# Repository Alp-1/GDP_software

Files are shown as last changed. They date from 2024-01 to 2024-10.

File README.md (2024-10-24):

banner-nana

This project aims to develop a rover that can navigate through different terrain in a forest environment autonomously.
The wiki containing more informatin about the rover can be found [here](https://github.com/Alp-1/NANA-Forest-Rover/wiki).

A more detailed account of the development process can be found [here](https://alportakci.com/projects/).

## The directory layout

    .
    ├── .vscode                 # VS Code settings
    ├── CAD Models              # CAD Models used in the project with attributions. 
    ├── ESP32                   # ESP32 code for ESP32-C3 dronebridge.
    ├── GPS                     # Script to start NTRIP caster.
    ├── low_level_control       # Low level control
    ├── lua_scripts             # Lua scripts uploaded in flight controller
    ├── navigation              # Autonomous navigation
    ├── pyrealsense             # Intel Realsense library required on Raspberry Pi
    ├── schematic               # Schematic of the low level controller
    ├── .gitignore
    ├── pyproject.toml          # Python dependencies
    └── README.md

### Installation
To run some code that are not hardware dependent on your local PC, you can run the following commands in Python (Version used: **3.10.5** in PC and Raspberry Pi):

(./ is the repo root directory)
```sh
$ pip install -e .
```

## Low Level Control
There are two components in the low level control i.e. the motor controller and the central hub. They are both implemented on the Raspberry Pi Pico using micropython. See the [README.md](low_level_control/README.md) in the low level control folder for more information.

## Autonomous navigation
The files in the pyrealsense folder may have to be in the same directory as the navigation scripts, depending on your installation.
Another option is to include the right package from local directory i.e. 
```python
from pyrealsense import pyrealsense2 as rs
``` 
To run the autonomous navigation script, use the following command in the navigation folder:
```sh
$ python navigation_final.py
```
## Research Poster

Poster

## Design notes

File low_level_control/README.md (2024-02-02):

# Low Level Control

There are two components in the low level control i.e. the motor controller and the central hub. They are both implemented on the Raspberry Pi Pico using micropython.

## The directory layout

    .
    ├── central_hub             # Central hub code
    ├── motor_controller        # Motor controller code
    ├── upy_mavlink             # MAVLink library for MicroPython
    ├── user_interface          # Output interface e.g. LED, RGB LED
    ├── protocol.py             # The protocol between the central hub and the motor controller.
    ├── tests                   # Tests that can be executed on host machine.
    └── README.md

## Loading/Running code on Pi Pico (IMPORTANT)
To load the code onto the Pi Pico, it is recommended to use Thonny IDE as they provide a GUI for the filesystem on the Pico. You can also use the command line tools (e.g. mpremote, rshell) to load the code onto the Pico.

First, load the common `user_interface` folder and `protocol.py` file onto the pico then load either the `motor_controller` or `central_hub` folder onto the pico depends on which component you want to run. Then, add respective `main.py` file to the root directory of the pico.

## Motor Controller
The motor controller is responsible for controlling the motors and reading off the sensors attached to the motor i.e. encodes and current sensors. It controls the motor using Sabertooth 2x12A through packetised serial protocol. The current sensors (ACS711EX) feeds ADC into the Pi Pico. The encoders are decoded in hardware using the Pi Pico's PIO.

## Central Hub
The central hub is responsible for controlling the modes of operation and the communication between the motor controller and the flight controller. This implementation offers three levels of autonomy i.e. direct RC control, Flight controller aided and fully autonomous mode. In all of these modes the Radio controller must be connected at all time.

## Running tests
The tests are implemented using pytest. To run the tests, run the following command in the root directory of the repo:
```sh
$ pytest
```
Alternatively, you can run the tests in vscode through the Testings tab.

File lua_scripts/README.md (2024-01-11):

# Lua Script

This folder contains the lua script used in this project

## Scripts
[rover-TerrainDetector.lua](https://github.com/ArduPilot/ardupilot/blob/master/libraries/AP_Scripting/examples/rover-TerrainDetector.lua) is used to slow down the rover when it encounters rough terrain.

- change the 'SPEED' parameter to change the value of speed of rough terrain. 

[rover-quicktune.lua](https://github.com/ArduPilot/ardupilot/blob/master/libraries/AP_Scripting/applets/rover-quicktune.lua) is used to tune the steering and speed controller gains for rover.
- The rover needs to be put in CIRCLE flight mode which is not achievable with QGround Control. Mission Planner is needed in this scenario.

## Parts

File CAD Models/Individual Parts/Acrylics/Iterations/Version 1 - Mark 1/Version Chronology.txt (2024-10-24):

formanufacture.zip
correctedmanufacture.zip
ForManufactureCDR.zip
23CDR.zip
Re23CDR.zip
fix.zip
ResSheld.cdr
Frontdraw v0.cdr

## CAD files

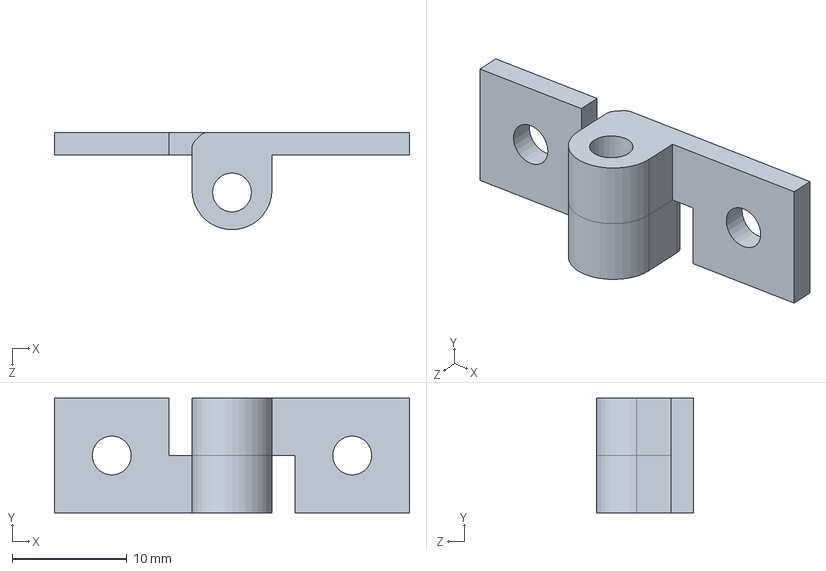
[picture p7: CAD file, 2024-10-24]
CAD Models/Individual Parts/Makerbeams/MakerBeam-hinge.SLDASM
31.0 x 10.0 x 8.50 mm
MakerBeam-hinge x 2

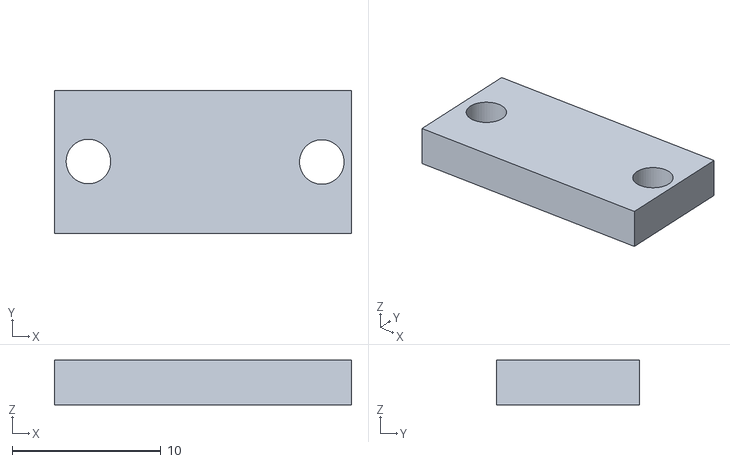
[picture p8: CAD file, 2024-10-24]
CAD Models/3D Print/cable holder v1.stl
20.0 x 9.60 x 3.00

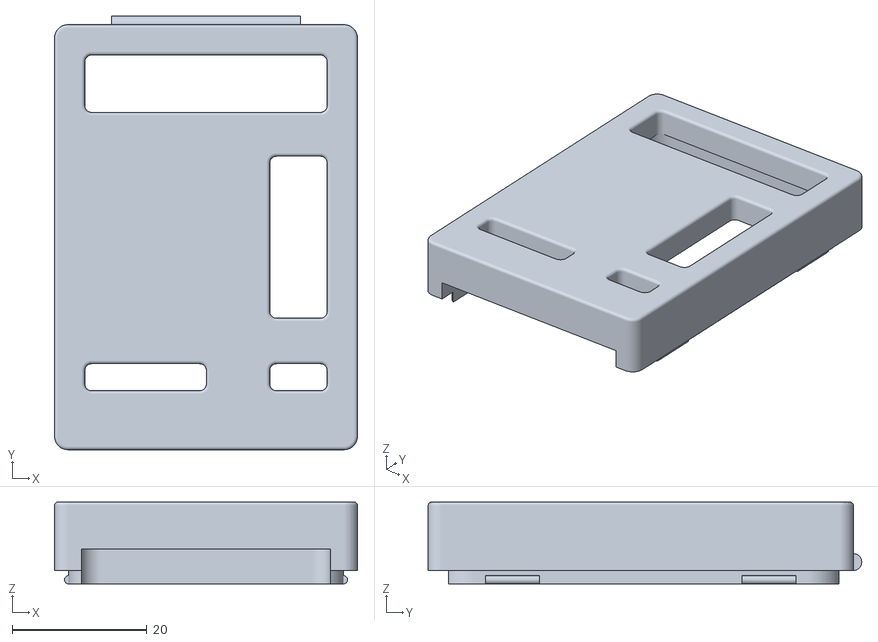
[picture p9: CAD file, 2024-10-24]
CAD Models/3D Print/Flight Controller Snap Mount/Top.stl
44.9 x 64.2 x 12.1

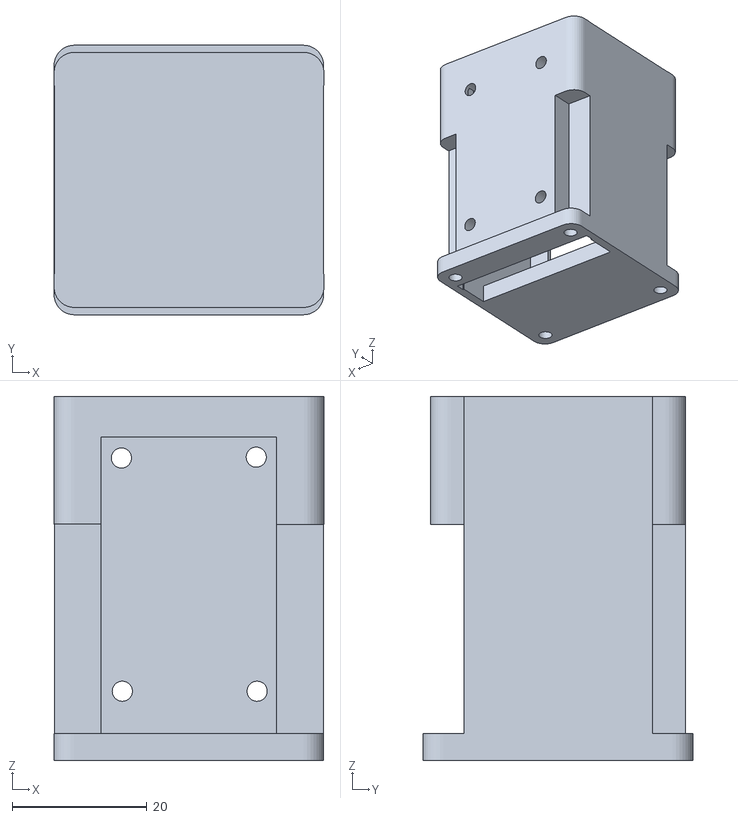
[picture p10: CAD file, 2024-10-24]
CAD Models/3D Print/Optical Flow/Optical Cube mk2.stl
40.1 x 40.0 x 54.0

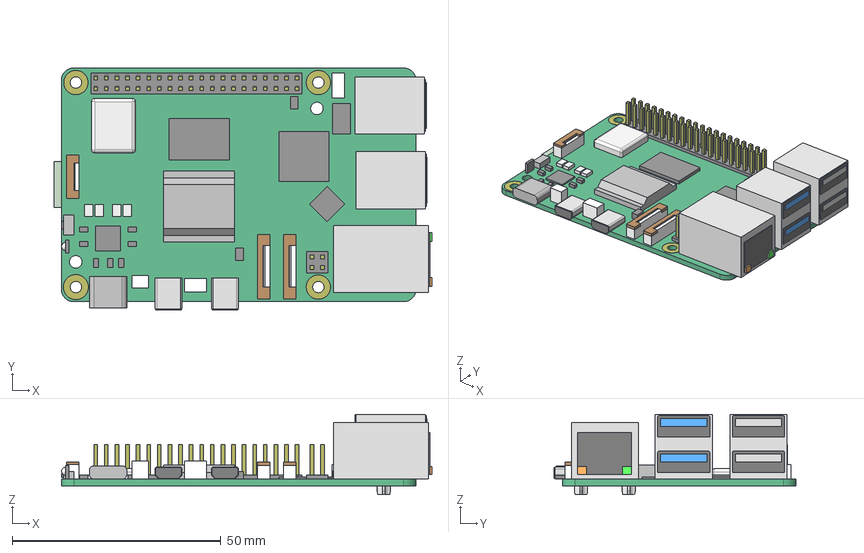
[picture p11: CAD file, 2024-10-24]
CAD Models/Individual Parts/Components/raspberry-pi-5-sbc-simple.step
90.6 x 58.0 x 19.2 mm
connector
CSI_DSI_connector x 2
ethernet
gpio
hdmi-micro x 2
IR
mounting-holes
pcb
pcba-components Geometry
chips
pcie
pmic
poe Geometry
poe-pins
pwr-connector
rp1
sd-card
switch
uart
usb-2-bank Geometry
usb2-port x 2
usb-3-bank Geometry
usb3-port x 2
usb-c

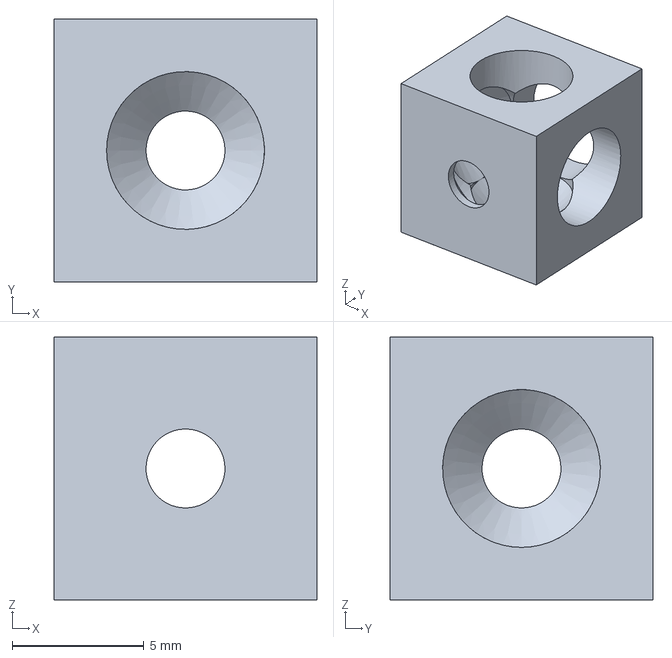
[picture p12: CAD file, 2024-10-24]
CAD Models/Individual Parts/Makerbeams/corner.stp
10.0 x 10.0 x 10.0 mm

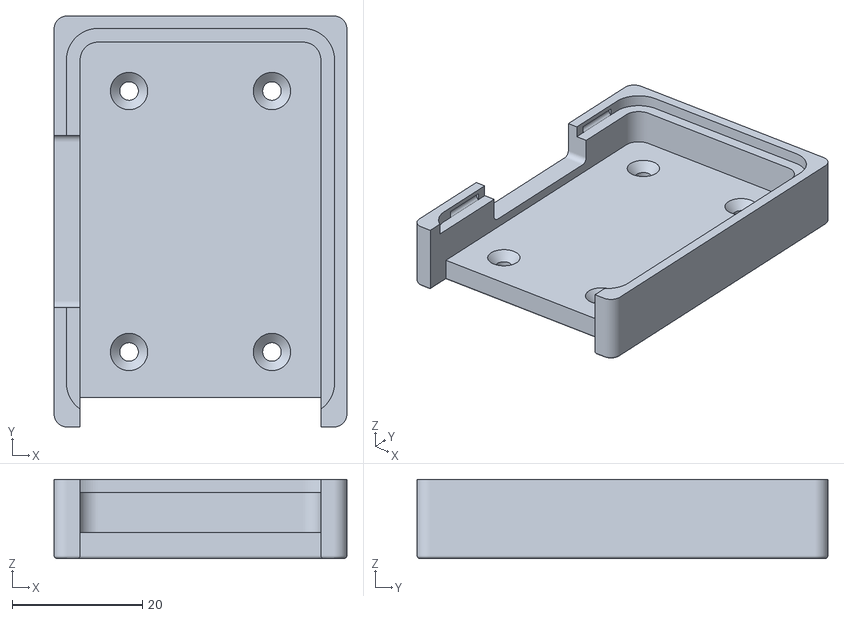
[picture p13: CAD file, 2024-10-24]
CAD Models/3D Print/Flight Controller Snap Mount/Bottom.stl
44.9 x 63.0 x 12.1

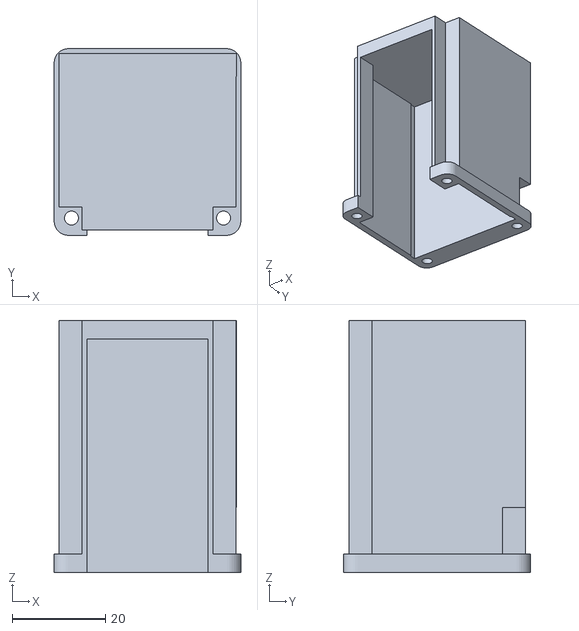
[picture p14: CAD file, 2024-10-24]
CAD Models/3D Print/Optical Flow/Optical Cube v1.stl
40.0 x 40.0 x 54.0

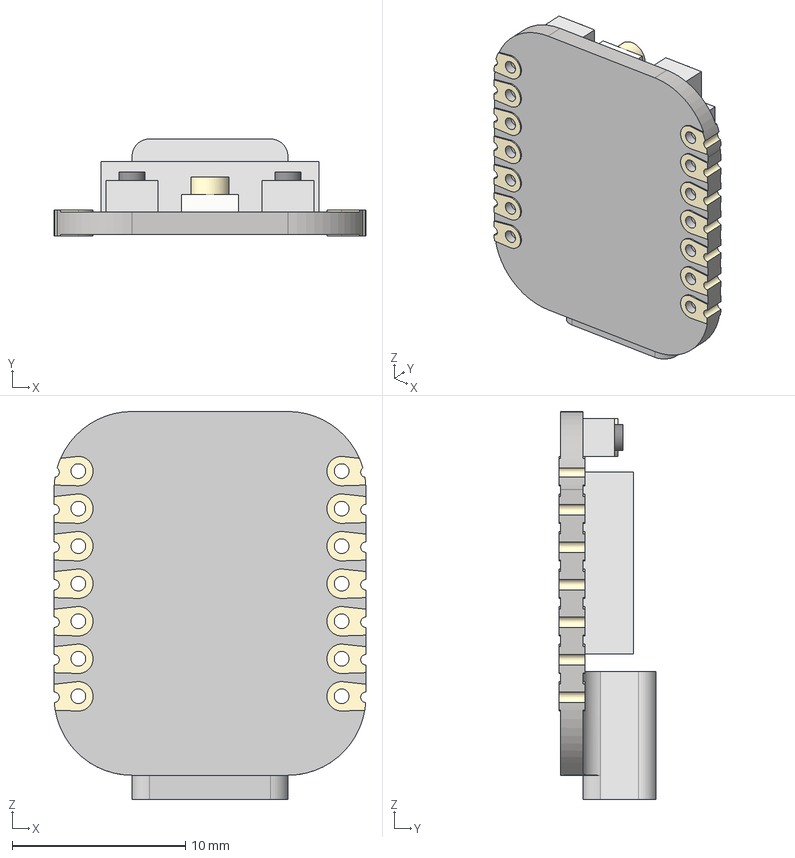
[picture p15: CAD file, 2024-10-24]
CAD Models/Individual Parts/Components/SEEED Esp32 C3 mini v2.step
18.0 x 5.60 x 22.4 mm

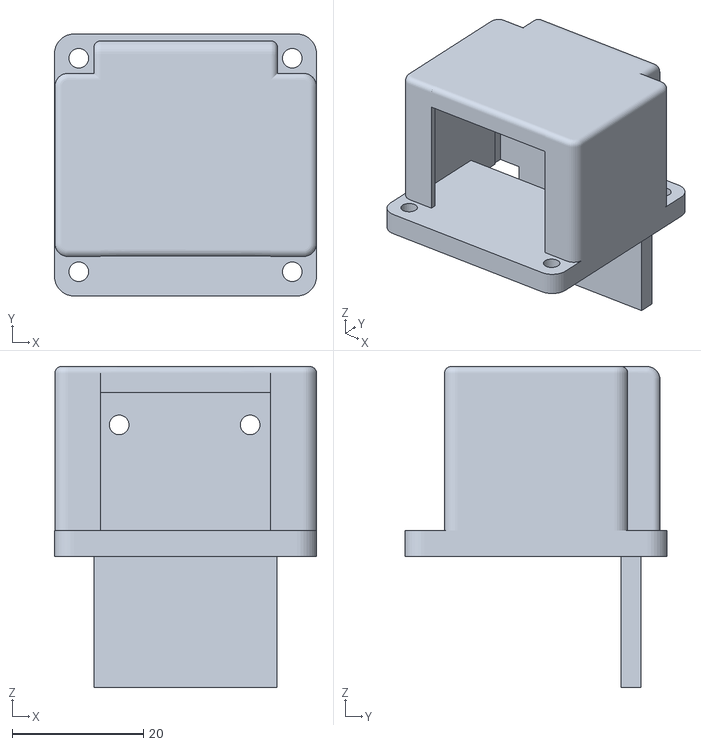
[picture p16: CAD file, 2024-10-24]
CAD Models/3D Print/Optical Flow/Optical Cube mk1 v4.stl
40.0 x 40.0 x 49.0

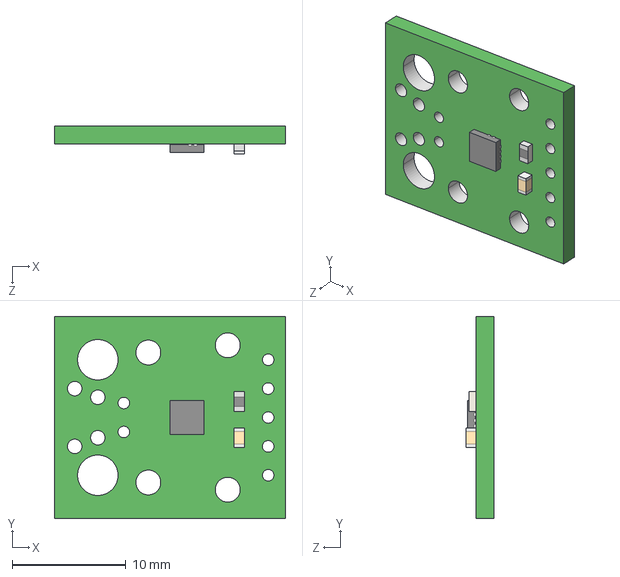
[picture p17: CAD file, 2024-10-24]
CAD Models/Individual Parts/Components/acs711ex-current-sensor-carrier.step
20.3 x 17.8 x 2.47 mm

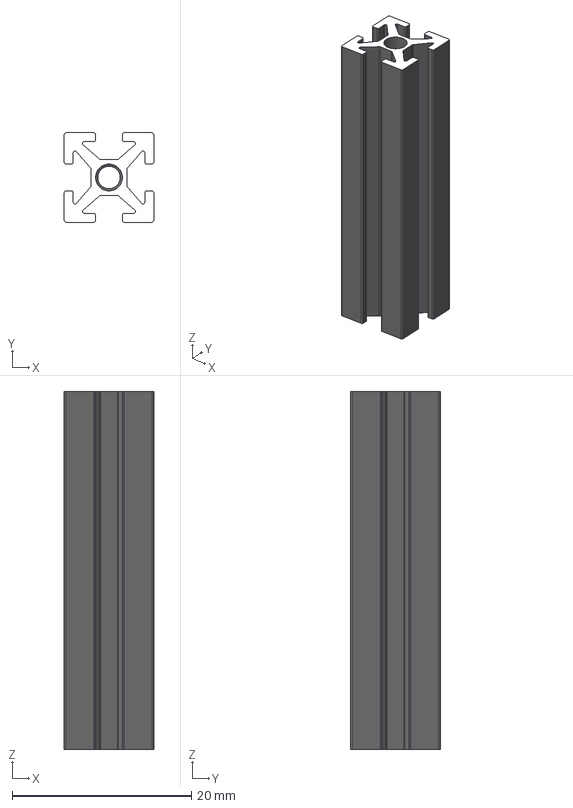
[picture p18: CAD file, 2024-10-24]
CAD Models/Individual Parts/Makerbeams/corner40.stp
10.0 x 10.0 x 40.0 mm

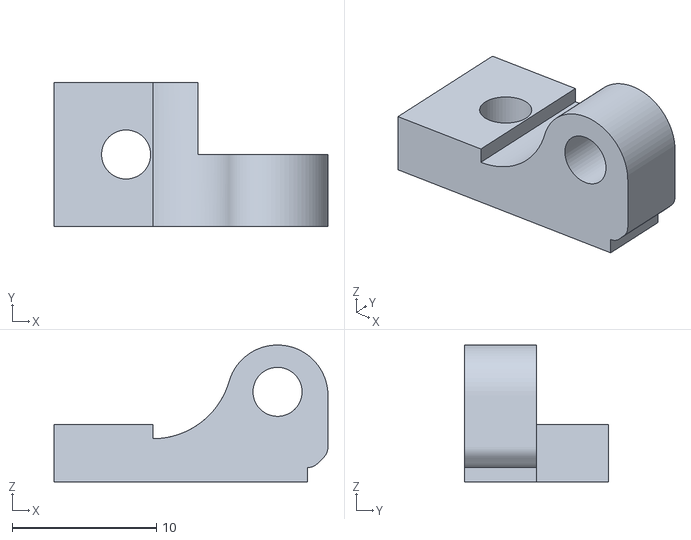
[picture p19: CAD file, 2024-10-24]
CAD Models/Individual Parts/Makerbeams/MakerBeam-hinge v2.stl
19.0 x 10.0 x 9.50

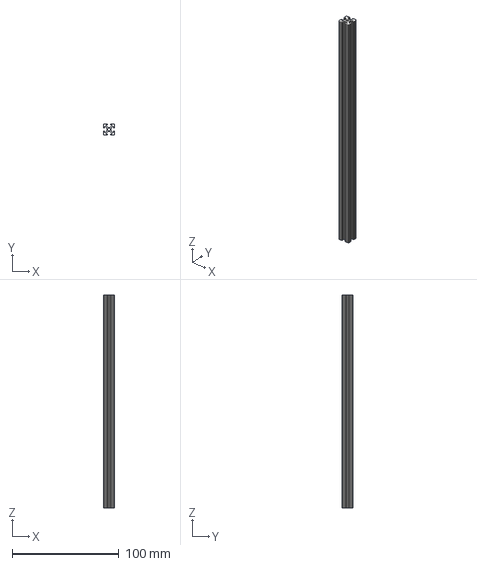
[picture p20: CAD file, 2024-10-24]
CAD Models/Individual Parts/Makerbeams/corner2.stp
10.0 x 10.0 x 200.0 mm

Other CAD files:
CAD Models/Individual Parts/Makerbeams/eye_plate_gs3212-05.stp
CAD Models/Individual Parts/Makerbeams/Makerbeam_T-Slot_Nut.step
CAD Models/3D Print/Cable Housing v2.f3z
CAD Models/3D Print/Optical Flow/Optical Cube mk1 v4.f3d
CAD Models/Individual Parts/Acrylics/Models/Front-Back v25.f3z
CAD Models/Individual Parts/Acrylics/Models/Front-Back1 v2.f3z
CAD Models/Individual Parts/Acrylics/Models/Side Panels v22.f3d
CAD Models/Individual Parts/Acrylics/Models/Top Cover v7.f3d
CAD Models/Individual Parts/Acrylics/Models/mount v12.f3d
CAD Models/Individual Parts/Acrylics/Models/rubber seal v1.f3d
CAD Models/Individual Parts/Acrylics/Models/shelf down v2.f3d
CAD Models/Individual Parts/Acrylics/Models/shelf small v2.f3d
CAD Models/Individual Parts/Aluminium Plates/Back v6.f3d
CAD Models/Individual Parts/Aluminium Plates/top half mount v2.f3d
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

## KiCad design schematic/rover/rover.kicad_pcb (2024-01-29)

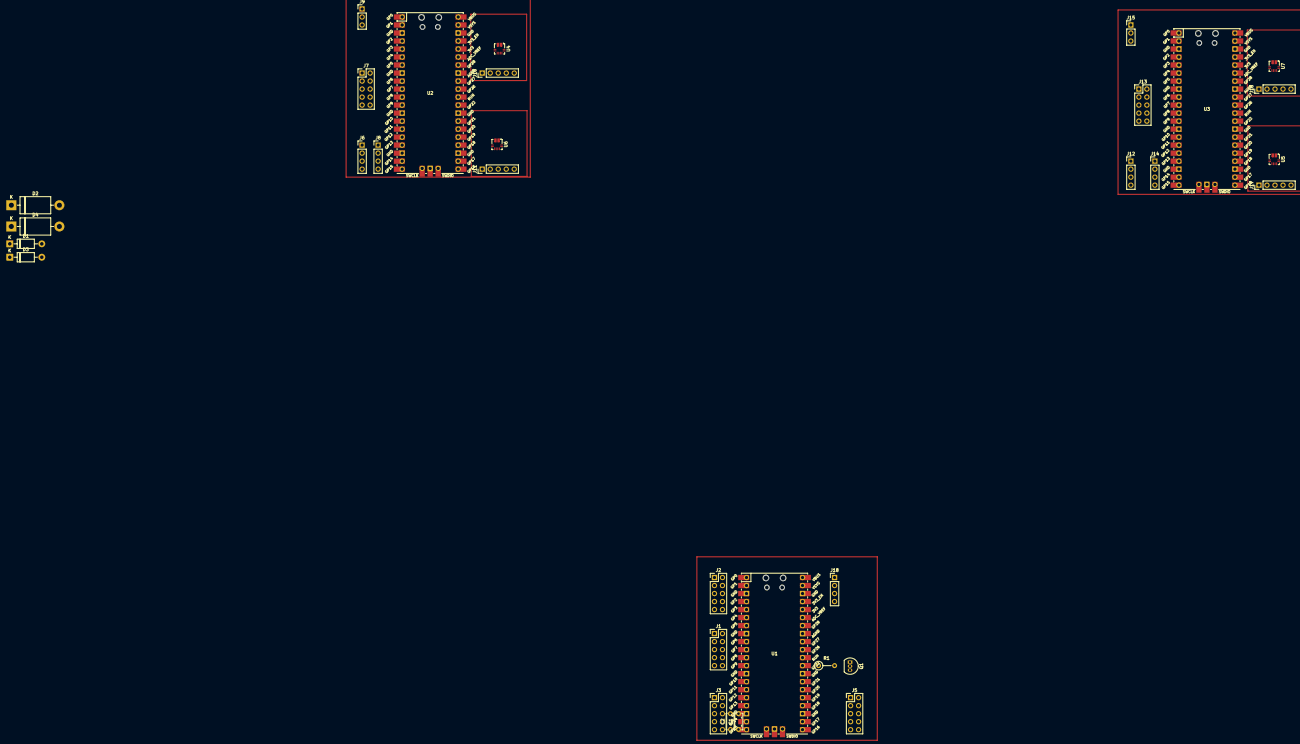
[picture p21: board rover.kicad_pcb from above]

Board: 2 copper layers, 32 parts (0 on the bottom side), 34 nets, no tracks yet.

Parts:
C1, C2: 3.3n; C_Disc_D5.0mm_W2.5mm_P5.00mm
D1, D3: 1N4733A; D_DO-41_SOD81_P10.16mm_Horizontal
D2, D4: 1N5820; D_DO-201AD_P15.24mm_Horizontal
J1: Front_Wheel_Conn; PinHeader_2x05_P2.54mm_Vertical
J2: Rear_Wheel_Conn; PinHeader_2x05_P2.54mm_Vertical
J3: Flight_Controller_Conn; PinHeader_2x05_P2.54mm_Vertical
J5: Receiver_Conn; PinHeader_2x05_P2.54mm_Vertical
J6, J12: Left_Encoder; PinHeader_1x04_P2.54mm_Vertical
J7, J13: Conn_02x05_Odd_Even; PinHeader_2x05_P2.54mm_Vertical
J8, J14: Right_Encoder; PinHeader_1x04_P2.54mm_Vertical
J9, J15: Conn_01x03_Socket; PinHeader_1x03_P2.54mm_Vertical
J10, J16: Right_Current_Sense; PinHeader_1x05_P2.54mm_Vertical
J11, J17: Left_Current_Sense; PinHeader_1x05_P2.54mm_Vertical
J18: Conn_01x04_Socket; PinHeader_1x04_P2.54mm_Vertical
Q1: BC547; TO-92_Inline
R1: 100k; R_Axial_DIN0207_L6.3mm_D2.5mm_P5.08mm_Vertical
U1, U2, U3: Pico; RPi_Pico_SMD_TH
U4, U5, U6, U7: ACS711xEXLT-31AB; Allegro_QFN-12-10-1EP_3x3mm_P0.5mm

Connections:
+3.3V: J5.3, J6.3, J8.3, J10.3, J11.3, J12.3, J14.3, J16.3, J17.3, U1.36 (3V3), U2.36 (3V3), U3.36 (3V3), U4.10 (VCC), U5.10 (VCC), U6.10 (VCC), U7.10 (VCC)
+5V: J9.1, J15.1, J18.2, U1.39 (VSYS)
/low level control/+5V_in: D2.1 (K), U2.39 (VSYS), U3.39 (VSYS)
/low level control/Sabertooth_front/S1: J9.2, U2.1 (GPIO0)
/low level control/Sabertooth_front/S2: J18.4, Q1.1 (C)
/low level control/Sabertooth_rear/S1: J15.2, U3.1 (GPIO0)
/low level control/central_hub/FC__SBUS: J3.1, J5.1
/low level control/central_hub/FC__Throttle_Left: C1.1, J3.8, U1.19 (GPIO14)
/low level control/central_hub/FC__Throttle_Right: C2.1, J3.10, U1.20 (GPIO15)
/low level control/central_hub/Flight_Controller__RX: J3.7, U1.22 (GPIO17)
/low level control/central_hub/Flight_Controller__TX: J3.9, U1.21 (GPIO16)
/low level control/central_hub/Front_Controller__RX: J1.8, J7.8, U1.2 (GPIO1), U2.6 (GPIO4)
/low level control/central_hub/Front_Controller__TX: J1.10, J7.10, U1.1 (GPIO0), U2.7 (GPIO5)
/low level control/central_hub/NeoPixelRGB: J18.1, U1.32 (GPIO27_ADC1)
/low level control/central_hub/OUTA_Left__Front: J1.7, J6.4, J7.7, U1.7 (GPIO5), U2.16 (GPIO12)
/low level control/central_hub/OUTA_Left__Rear: J2.7, J3.3, J12.4, J13.7, U1.14 (GPIO10), U3.16 (GPIO12)
/low level control/central_hub/OUTA_Right__Front: J1.6, J7.6, J8.4, U1.5 (GPIO3), U2.20 (GPIO15)
/low level control/central_hub/OUTA_Right__Rear: J2.6, J3.4, J13.6, J14.4, U1.17 (GPIO13), U3.20 (GPIO15)
/low level control/central_hub/OUTB_Left__Front: J1.9, J6.1, J7.9, U1.6 (GPIO4), U2.17 (GPIO13)
/low level control/central_hub/OUTB_Left__Rear: J2.9, J3.5, J12.1, J13.9, U1.15 (GPIO11), U3.17 (GPIO13)
/low level control/central_hub/OUTB_Right__Front: J1.4, J7.4, J8.1, U1.4 (GPIO2), U2.19 (GPIO14)
/low level control/central_hub/OUTB_Right__Rear: J2.4, J3.2, J13.4, J14.1, U1.16 (GPIO12), U3.19 (GPIO14)
/low level control/central_hub/Rear_Controller__RX: J2.8, J13.8, U1.12 (GPIO9), U3.6 (GPIO4)
/low level control/central_hub/Rear_Controller__TX: J2.10, J13.10, U1.11 (GPIO8), U3.7 (GPIO5)
/low level control/central_hub/Receiver__PPM: J5.2, U1.27 (GPIO21)
/power supply/5V_RaspberryPi: D3.1 (K), D4.2 (A)
GND: C1.2, C2.2, D1.2 (A), D3.2 (A), J1.2, J2.2, J3.6, J5.5, J6.2, J7.2, J8.2, J9.3, J10.1, J10.2, J11.1, J11.2, J12.2, J13.2, J14.2, J15.3, J16.1, J16.2, J17.1, J17.2, J18.3, Q1.3 (E), U1.3 (GND), U1.8 (GND), U1.13 (GND), U1.18 (GND), U1.23 (GND), U1.28 (GND), U1.38 (GND), U2.3 (GND), U2.18 (GND), U2.23 (GND), U2.28 (GND), U2.38 (GND), U3.3 (GND), U3.18 (GND), U3.23 (GND), U3.28 (GND), U3.38 (GND), U4.3 (GND), U5.3 (GND), U6.3 (GND), U7.3 (GND)
unnamed: D1.1 (K), D2.2 (A)
unnamed: J10.4, U2.32 (GPIO27_ADC1), U6.9 (VIOUT)
unnamed: J11.4, U2.34 (GPIO28_ADC2), U4.9 (VIOUT)
unnamed: J16.4, U3.32 (GPIO27_ADC1), U7.9 (VIOUT)
unnamed: J17.4, U3.34 (GPIO28_ADC2), U5.9 (VIOUT)
unnamed: Q1.2 (B), R1.2
unnamed: R1.1, U1.29 (GPIO22)

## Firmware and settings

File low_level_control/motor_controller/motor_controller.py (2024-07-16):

"""The main motor controller code"""

import time
from machine import Pin, UART
from motor_controller.motor_sensor import MotorSensing
from motor_controller.sabertooth import Sabertooth
from motor_controller.pid import PID
from protocol import Commands
from user_interface.led import OnBoardLED

LEFT_MOTOR_ID = 2
LEFT_MOTOR_ENCODER_PIN = 12
LEFT_MOTOR_SM = 0
LEFT_MOTOR_CURRENT_PIN = 1

RIGHT_MOTOR_ID = 1
RIGHT_MOTOR_ENCODER_PIN = 14
RIGHT_MOTOR_SM = 1
RIGHT_MOTOR_CURRENT_PIN = 2

CENTRAL_HUB_TX_PIN = 4
CENTRAL_HUB_RX_PIN = 5

SABERTOOTH_ADDRESS = 128
SABERTOOTH_BAUDRATE = 9600
SABERTOOTH_TX_PIN = 0
SABERTOOTH_RX_PIN = 1  # Irrelevant

BYPASS_ENCODER = True  # Remove this switch after encoder is fixed


class MotorController:
    """Controls the motor speed using the signals coming from the central hub"""

    THRESHOLD_CURRENT = 15  # Amps
    # Need to be at least twice the encoders' measurement time
    PID_PERIOD_MS = 200
    MAIN_LOOP_PERIOD_MS = 1
    SENSOR_UPDATE_PERIOD_MS = 1000
    # Period before the central hub is considered disconnected
    CENTRAL_HUB_TIMEOUT_MS = 1000

    # Speed setpoint range
    MAX_SPEED_RPM = 165
    MIN_SPEED_RPM = -165
    # The maximum range of the PID controller
    MAX_PID_RANGE = (MIN_SPEED_RPM, MAX_SPEED_RPM)
    PID_DEADZONE = 5

    # Attribute to reverse the output of the motor
    # to compensate for the motor being mounted in reverse
    REVERSE_OUTPUT = True

    # Motor driver drive modes
    MIXED = 0
    INDEPENDENT_MOTOR = 1

    def __init__(
        self,
        motor_driver_serial=None,
        central_hub_interface=None,
        left_motor=None,
        right_motor=None,
        motor_driver=None,
    ):
        """Initialize the motor controller.
        The parameters are used for testing purposes,
        please use the default values for normal operation."""
        # Initialize the motors
        self.motor_driver_serial = (
            UART(
                0,
                baudrate=SABERTOOTH_BAUDRATE,
                tx=Pin(SABERTOOTH_TX_PIN),
                rx=Pin(SABERTOOTH_RX_PIN),
            )
            if motor_driver_serial is None
            else motor_driver_serial
        )
        self.left_motor = (
            MotorSensing(
                LEFT_MOTOR_ENCODER_PIN,
                LEFT_MOTOR_SM,
                LEFT_MOTOR_CURRENT_PIN,
                invert_current=True,
            )
            if left_motor is None
            else left_motor
        )
        self.right_motor = (
            MotorSensing(
                RIGHT_MOTOR_ENCODER_PIN,
                RIGHT_MOTOR_SM,
                RIGHT_MOTOR_CURRENT_PIN,
                invert_current=True,
            )
            if right_motor is None
            else right_motor
        )
        self.motor_driver: Sabertooth = (
            Sabertooth(
                self.motor_driver_serial,
                address=SABERTOOTH_ADDRESS,
            )
            if motor_driver is None
            else motor_driver
        )
        self.central_hub_interface = (
            UART(
                1,
                baudrate=4800,
                tx=Pin(CENTRAL_HUB_TX_PIN),
                rx=Pin(CENTRAL_HUB_RX_PIN),
            )
            if central_hub_interface is None
            else central_hub_interface
        )

        self.left_speed_command = 0
        self.right_speed_command = 0
        self.turn = 0
        self.mixed_clipped_range = (-100, 100)

        self.current_drive_mode = self.MIXED

        self.pid_left = PID(
            Kp=0.25,
            Ki=0.001,
            Kd=0.005,
            setpoint=0,
            sample_time=self.PID_PERIOD_MS,
            output_limits=self.MAX_PID_RANGE,
            time_fn=time.ticks_ms,
        )
        self.pid_right = PID(
            Kp=0.25,
            Ki=0.001,
            Kd=0.005,
            setpoint=0,
            sample_time=self.PID_PERIOD_MS,
            output_limits=self.MAX_PID_RANGE,
            time_fn=time.ticks_ms,
        )

    def drive(self, left_speed: float, right_speed: float, turn=None):
        """Drive the motors at a given speed

        Parameters
        ----------
        left_speed: float
            The speed to drive the left motor at (-100: full reverse, 0: stop, 100: full forward)
        right_speed: float
            The speed to drive the right motor at (-100: full reverse, 0: stop, 100: full forward)
        turn: float
            The turn value (-100: full left, 0: straight, 100: full right)
            If this is not None, the rover will be driven in mixed mode
            using only values from left_speed and turn, i.e. the
            right_speed value will be ignored. (Assume this only happens in RC mode)
        """
        if self.REVERSE_OUTPUT:
            left_speed = -left_speed
            right_speed = -right_speed
            turn = -turn if turn is not None else None

        if turn is not None:
            left_speed = self.map_range(
                left_speed,
                -100,
                100,
                self.mixed_clipped_range[0],
                self.mixed_clipped_range[1],
            )
            turn = self.map_range(
                turn,
                -100,
                100,
                self.mixed_clipped_range[0],
                self.mixed_clipped_range[1],
            )
            self.motor_driver.drive_both(left_speed, turn)
        else:
            if BYPASS_ENCODER:
                left_speed = self.map_range(
                    left_speed,
                    -100,
                    100,
                    self.mixed_clipped_range[0],
                    self.mixed_clipped_range[1],
                )
                right_speed = self.map_range(
                    right_speed,
                    -100,
                    100,
                    self.mixed_clipped_range[0],
                    self.mixed_clipped_range[1],
                )
            self.motor_driver.drive(LEFT_MOTOR_ID, left_speed)
            self.motor_driver.drive(RIGHT_MOTOR_ID, right_speed)

    def overcurrent_protection(self):
        """Reacts to overcurrent depending on the mode.

        If the current mode is mixed, the direct output will be clipped (both turn and speed)
        If the current mode is individual, the pid output will be reduced
        """
        if self.current_drive_mode == self.MIXED or BYPASS_ENCODER:
            prev_range = self.mixed_clipped_range[1] - self.mixed_clipped_range[0]
            left_clipped_range = self.current_to_output_map(
                self.left_motor.current, prev_range=prev_range
            )
            right_clipped_range = self.current_to_output_map(
                self.right_motor.current, prev_range=prev_range
            )
            self.mixed_clipped_range = (
                max(left_clipped_range[0], right_clipped_range[0]),
                min(left_clipped_range[1], right_clipped_range[1]),
            )
            return self.mixed_clipped_range
        elif self.current_drive_mode == self.INDEPENDENT_MOTOR:
            max_range = self.MAX_PID_RANGE[1] - self.MAX_PID_RANGE[0]
            left_prev_range = (
                self.pid_left.output_limits[1] - self.pid_left.output_limits[0]
            )
            right_prev_range = (
                self.pid_right.output_limits[1] - self.pid_right.output_limits[0]
            )
            self.pid_left.output_limits = self.current_to_output_map(
                self.left_motor.current,
                prev_range=left_prev_range,
                max_range=max_range,
            )
            self.pid_right.output_limits = self.current_to_output_map(
                self.right_motor.current,
                prev_range=right_prev_range,
                max_range=max_range,
            )
            return self.pid_left.output_limits, self.pid_right.output_limits

    def current_to_output_map(self, current, prev_range, max_range=200):
        """Return the clipped output range of the controller"""
        # No output cap for current less than 34% of the threshold (5A for 15A threshold)
        if abs(current) < 0.34 * self.THRESHOLD_CURRENT and prev_range == max_range:
            return (-max_range / 2, max_range / 2)
        # Generate a range from 0 to 1
        normalised_clipped_range = (
            self.THRESHOLD_CURRENT - abs(current)
        ) / self.THRESHOLD_CURRENT
        # Prevent negative values
        normalised_clipped_range = max(normalised_clipped_range, 0)
        # Slowly increase the range to prevent aggressive oscillation
        clipped_range = normalised_clipped_range * (prev_range + 10) * 1.2
        clipped_range = min(clipped_range, max_range)
        return (-clipped_range / 2, clipped_range / 2)  # Assume the output is symmetric

    @staticmethod
    def map_range(x, in_min, in_max, out_min, out_max):
        """Map a value from one range to another. Will return a float"""
        return (x - in_min) * (out_max - out_min) / (in_max - in_min) + out_min

    def send_currents(self):
        """Send the current values to the central hub"""
        currents = (self.left_motor.current, self.right_motor.current)
        out_command = Commands.generate_command(
            (
                Commands.RESP_CURRENTS,
                currents,
            )
        )
        self.central_hub_interface.write(out_command)

    def send_encoders(self):
        """Send the encoder values to the central hub"""
        encoders = (
            self.left_motor.encoder.position(),
            self.right_motor.encoder.position(),
        )
        out_command = Commands.generate_command(
            (
                Commands.RESP_ENCODERS,
                encoders,
            )
        )
        self.central_hub_interface.write(out_command)

    def execute_command(self, command):
        """Parse the command from the central hub. The command can be:

        Parameters
        ----------
        command: bytes
            The command from the central hub

        Returns
        -------
        bool
            True if the command is valid, False otherwise
        """
        valid = False
        parsed = Commands.parse_command(command)
        if parsed is None:
            return False
        else:
            valid = True
            command_type, command_value = parsed
            # print(command_type, command_value)
            if command_type == Commands.SET_SPEED_MIXED:
                self.left_speed_command, self.turn = command_value
                print(
                    "Speed: {:.2f} Turn: {:.2f}".format(
                        self.left_speed_command, self.turn
                    )
                )
                self.drive(self.left_speed_command, 0, self.turn)
                self.detect_mode_change()
            elif command_type == Commands.SET_SPEED_LEFT_RIGHT:
                self.turn = None
                # print("command_value", command_value)
                self.left_speed_command = command_value[0]
                self.right_speed_command = command_value[1]
                self.set_pid_setpoint(
                    self.pid_left, self.setpoint_to_rpm(self.left_speed_command)
                )
                self.set_pid_setpoint(
                    self.pid_right, self.setpoint_to_rpm(self.right_speed_command)
                )
                print(
                    "Left: {:.2f} Right: {:.2f}".format(
                        self.left_speed_command, self.right_speed_command
                    )
                )
                self.pid_update()
                self.drive(self.left_speed_command, self.right_speed_command)
                self.detect_mode_change()
            elif command_type == Commands.UNKNOWN:
                print("Unknown command")
                valid = False
            else:
                # Ignore other commands
                valid = False

        return valid

    @classmethod
    def set_pid_setpoint(cls, pid, value):
        """Disable PID controller if the value is within the deadzone. Enable otherwise"""
        if abs(value) < cls.PID_DEADZONE:
            pid.setpoint = 0
            pid.auto_mode = False
        else:
            pid.setpoint = value
            pid.auto_mode = True

    def detect_mode_change(self):
        """Allow the class to set the timer period once per mode change"""
        if self.current_drive_mode != self.MIXED and self.turn is not None:
            # mode change
            self.current_drive_mode = self.MIXED
            OnBoardLED.set_period_ms(2000)
        elif self.current_drive_mode != self.INDEPENDENT_MOTOR and self.turn is None:
            self.current_drive_mode = self.INDEPENDENT_MOTOR
            OnBoardLED.set_period_ms(1000)

    @staticmethod
    def rpm_to_setpoint(rpm):
        """Convert a rpm value to a setpoint within the range of -100 to 100"""
        setpoint = (rpm - MotorController.MIN_SPEED_RPM) / (
            MotorController.MAX_SPEED_RPM - MotorController.MIN_SPEED_RPM
        ) * 200 - 100
        return max(min(setpoint, 100), -100)

    @staticmethod
    def setpoint_to_rpm(setpoint):
        """Convert a setpoint value within the range of -100 to 100 to a rpm value"""
        rpm = (setpoint + 100) / 200 * (
            MotorController.MAX_SPEED_RPM - MotorController.MIN_SPEED_RPM
        ) + MotorController.MIN_SPEED_RPM
        return max(
            min(rpm, MotorController.MAX_SPEED_RPM), MotorController.MIN_SPEED_RPM
        )

    def central_hub_timeout_handler(self):
        """Stop the motors when the central hub timeout"""
        self.left_speed_command = 0
        self.right_speed_command = 0
        if self.current_drive_mode == self.MIXED:
            self.turn = 0
            self.drive(self.left_speed_command, 0, self.turn)
        elif self.current_drive_mode == self.INDEPENDENT_MOTOR:
            if BYPASS_ENCODER:
                self.drive(0, 0)
            else:
                self.set_pid_setpoint(self.pid_left, self.left_speed_command)
                self.set_pid_setpoint(self.pid_right, self.right_speed_command)
                self.pid_update()
        else:
            print("Unknown mode")

    def main_control_loop(self):
        """Inteprets the commands from the central hub and controls the motors"""
        OnBoardLED.on()
        prev_sensor_time = time.ticks_ms()
        last_command_time = time.ticks_ms()

        while True:  # Can be changed to use async to allow other tasks to run
            # The command will latch until a new command is received
            self.overcurrent_protection()
            if (
                time.ticks_diff(time.ticks_ms(), prev_sensor_time)
                > self.SENSOR_UPDATE_PERIOD_MS
            ):
                self.send_currents()
                self.send_encoders()
                prev_sensor_time = time.ticks_ms()

            if self.central_hub_interface.any() != 0:
                command = self.central_hub_interface.read()
                self.execute_command(command)
                last_command_time = time.ticks_ms()
            else:
                # Try to parse the remaining data in the buffer
                self.execute_command(b"")
                # Check if the central hub is disconnected
                if (
                    time.ticks_diff(time.ticks_ms(), last_command_time)
                    > self.CENTRAL_HUB_TIMEOUT_MS
                ):
                    self.central_hub_timeout_handler()

            if self.current_drive_mode == self.MIXED:
                self.drive(self.left_speed_command, 0, self.turn)
            elif self.current_drive_mode == self.INDEPENDENT_MOTOR:
                # Run the PID control loop until a new command is received
                if BYPASS_ENCODER:
                    self.drive(self.left_speed_command, self.right_speed_command)
                else:
                    self.pid_update()

            time.sleep_ms(self.MAIN_LOOP_PERIOD_MS)

    def pid_update(self):
        """Execute one iteration of the PID control loop"""
        if BYPASS_ENCODER:
            return
        current_speed = [self.left_motor.rpm, self.right_motor.rpm]
        left_input_rpm = 0
        right_input_rpm = 0
        if self.pid_left.auto_mode:
            left_input_rpm = self.pid_left(current_speed[0])
        if self.pid_right.auto_mode:
            right_input_rpm = self.pid_right(current_speed[1])
        # Clip the speed command to the maximum speed
        self.left_speed_command = self.rpm_to_setpoint(left_input_rpm)
        self.right_speed_command = self.rpm_to_setpoint(right_input_rpm)
        self.drive(self.left_speed_command, self.right_speed_command)
        return self.left_speed_command, self.right_speed_command

    def _pid_until_stable(
        self,
        left_target_speed=0,
        right_target_speed=0,
        rpm_error_threshold=1,
        timeout=1000,
    ):
        """Execute the PID control loop until the speed is stable
        Use for testing purposes
        """
        self.pid_left.reset()
        self.pid_right.reset()
        self.current_drive_mode = self.INDEPENDENT_MOTOR
        last_time = time.ticks_ms()
        self.set_pid_setpoint(self.pid_left, left_target_speed)
        self.set_pid_setpoint(self.pid_right, right_target_speed)
        iteration = 0
        try:
            while time.ticks_diff(time.ticks_ms(), last_time) < timeout:
                iteration += 1
                start = time.ticks_us()
                print("Limits: ", self.overcurrent_protection())
                self.pid_update()
                last_error = (self.pid_left._last_error, self.pid_right._last_error)
                print(
                    "Iteration {}: {} us".format(
                        iteration, time.ticks_diff(time.ticks_us(), start)
                    )
                )
                print("Last error at iteration {}: {}".format(iteration, last_error))
                print(
                    "Drive: {:.2f} {:.2f}".format(
                        self.left_speed_command, self.right_speed_command
                    )
                )
                if rpm_error_threshold > 0 and all(
                    abs(error) < rpm_error_threshold
                    for error in last_error
                    if error is not None
                ):
                    break
                time.sleep_ms(self.PID_PERIOD_MS)
        except KeyboardInterrupt:
            print("Keyboard interrupt")
        finally:
            self.drive(0, 0)


if __name__ == "__main__":
    motor_controller = MotorController()
    motor_controller.main_control_loop()

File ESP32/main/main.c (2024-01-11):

/*
 *   This file is part of DroneBridge: https://github.com/DroneBridge/ESP32
 *
 *   Copyright 2018 Wolfgang Christl
 *
 *   Licensed under the Apache License, Version 2.0 (the "License");
 *   you may not use this file except in compliance with the License.
 *   You may obtain a copy of the License at
 *
 *   http://www.apache.org/licenses/LICENSE-2.0
 *
 *   Unless required by applicable law or agreed to in writing, software
 *   distributed under the License is distributed on an "AS IS" BASIS,
 *   WITHOUT WARRANTIES OR CONDITIONS OF ANY KIND, either express or implied.
 *   See the License for the specific language governing permissions and
 *   limitations under the License.
 *
 */

#include <stdio.h>
#include <nvs_flash.h>
#include <esp_wifi_types.h>
#include <mdns.h>
#include <string.h>
#include <driver/gpio.h>
#include <lwip/apps/netbiosns.h>

#include "freertos/event_groups.h"
#include "esp_wifi.h"
#include "esp_wifi_types.h"
#include "esp_log.h"
#include "esp_event.h"
#include "db_esp32_control.h"
#include "http_server.h"
#include "db_esp32_comm.h"
#include "db_protocol.h"
#include "esp_vfs_semihost.h"
#include "esp_spiffs.h"
#include "http_server.h"
#include "main.h"

#define NVS_NAMESPACE "settings"
// #define USE_ALT_UART_CONFIG // for boards that have flash connected to GPIO 17/16 - will crash otherwise

static const char *TAG = "DB_ESP32";

uint8_t DB_WIFI_MODE = 1; // 1=Wifi AP mode, 2=Wifi client mode
uint8_t DEFAULT_SSID[32] = "DroneBridge ESP32";
uint8_t DEFAULT_PWD[64] = "dronebridge";
char DEFAULT_AP_IP[32] = "192.168.2.1";
char CURRENT_CLIENT_IP[32] = "192.168.2.1";
uint8_t DEFAULT_CHANNEL = 6;
uint8_t SERIAL_PROTOCOL = 4;  // 1=MSP, 4=MAVLink/transparent
# ifdef USE_ALT_UART_CONFIG
uint8_t DB_UART_PIN_TX = GPIO_NUM_33;
uint8_t DB_UART_PIN_RX = GPIO_NUM_32;
# else
uint8_t DB_UART_PIN_TX = GPIO_NUM_21;
uint8_t DB_UART_PIN_RX = GPIO_NUM_20;
#endif
int32_t DB_UART_BAUD_RATE = 115200;
//uint16_t TRANSPARENT_BUF_SIZE = 64;
uint16_t TRANSPARENT_BUF_SIZE = 1024;
uint8_t LTM_FRAME_NUM_BUFFER = 1;
uint8_t MSP_LTM_SAMEPORT = 0;

// Wifi client mode vars
int WIFI_ESP_MAXIMUM_RETRY = 100;
static int s_retry_num = 0;
static EventGroupHandle_t s_wifi_event_group;
#define WIFI_CONNECTED_BIT BIT0
#define WIFI_FAIL_BIT      BIT1

static void wifi_event_handler(void *arg, esp_event_base_t event_base, int32_t event_id, void *event_data) {
    if (event_id == WIFI_EVENT_AP_STACONNECTED) {
        wifi_event_ap_staconnected_t *event = (wifi_event_ap_staconnected_t *) event_data;
        ESP_LOGI(TAG, "Client connected - station:"MACSTR", AID=%d", MAC2STR(event->mac), event->aid);
    } else if (event_id == WIFI_EVENT_AP_STADISCONNECTED) {
        wifi_event_ap_stadisconnected_t *event = (wifi_event_ap_stadisconnected_t *) event_data;
        ESP_LOGI(TAG, "Client disconnected - station:"MACSTR", AID=%d", MAC2STR(event->mac), event->aid);
    } else if (event_id == WIFI_EVENT_AP_START) {
        ESP_LOGI(TAG, "AP started!");
    } else if (event_id == WIFI_EVENT_AP_STOP) {
        ESP_LOGI(TAG, "AP stopped!");
    }
    // Wifi client mode events
    if (event_base == WIFI_EVENT && event_id == WIFI_EVENT_STA_START) {
        esp_wifi_connect();
    } else if (event_base == WIFI_EVENT && event_id == WIFI_EVENT_STA_DISCONNECTED) {
        if (s_retry_num < WIFI_ESP_MAXIMUM_RETRY) {
            esp_wifi_connect();
            s_retry_num++;
            ESP_LOGI(TAG, "Retry to connect to the AP");
        } else {
            xEventGroupSetBits(s_wifi_event_group, WIFI_FAIL_BIT);
        }
        ESP_LOGI(TAG,"Connecting to the AP failed");
    } else if (event_base == IP_EVENT && event_id == IP_EVENT_STA_GOT_IP) {
        ip_event_got_ip_t* event = (ip_event_got_ip_t*) event_data;
        ESP_LOGI(TAG, "Got IP:" IPSTR, IP2STR(&event->ip_info.ip));
        sprintf(CURRENT_CLIENT_IP, IPSTR, IP2STR(&event->ip_info.ip));
        s_retry_num = 0;
        xEventGroupSetBits(s_wifi_event_group, WIFI_CONNECTED_BIT);
    }
}

void start_mdns_service() {
    //initialize mDNS service
    esp_err_t err = mdns_init();
    if (err) {
        printf("MDNS Init failed: %d\n", err);
        return;
    }
    ESP_ERROR_CHECK(mdns_hostname_set("dronebridge"));
    ESP_ERROR_CHECK(mdns_instance_name_set("DroneBridge for ESP32"));

    ESP_ERROR_CHECK(mdns_service_add(NULL, "_http", "_tcp", 80, NULL, 0));
    ESP_ERROR_CHECK(mdns_service_add(NULL, "_db_proxy", "_tcp", APP_PORT_PROXY, NULL, 0));
    ESP_ERROR_CHECK(mdns_service_add(NULL, "_db_comm", "_tcp", 1604, NULL, 0));
    ESP_ERROR_CHECK(mdns_service_instance_name_set("_http", "_tcp", "DroneBridge for ESP32"));
}

#if CONFIG_WEB_DEPLOY_SEMIHOST
esp_err_t init_fs(void) {
    esp_err_t ret = esp_vfs_semihost_register(CONFIG_WEB_MOUNT_POINT, CONFIG_HOST_PATH_TO_MOUNT);
    if (ret != ESP_OK) {
        ESP_LOGE(TAG, "Failed to register semihost driver (%s)!", esp_err_to_name(ret));
        return ESP_FAIL;
    }
    return ESP_OK;
}
#endif


#if CONFIG_WEB_DEPLOY_SF

esp_err_t init_fs(void) {
    esp_vfs_spiffs_conf_t conf = {
            .base_path = CONFIG_WEB_MOUNT_POINT,
            .partition_label = NULL,
            .max_files = 5,
            .format_if_mount_failed = false
    };
    esp_err_t ret = esp_vfs_spiffs_register(&conf);

    if (ret != ESP_OK) {
        if (ret == ESP_FAIL) {
            ESP_LOGE(TAG, "Failed to mount or format filesystem");
        } else if (ret == ESP_ERR_NOT_FOUND) {
            ESP_LOGE(TAG, "Failed to find SPIFFS partition");
        } else {
            ESP_LOGE(TAG, "Failed to initialize SPIFFS (%s)", esp_err_to_name(ret));
        }
        return ESP_FAIL;
    }

    size_t total = 0, used = 0;
    ret = esp_spiffs_info(NULL, &total, &used);
    if (ret != ESP_OK) {
        ESP_LOGE(TAG, "Failed to get SPIFFS partition information (%s)", esp_err_to_name(ret));
    } else {
        ESP_LOGI(TAG, "Partition size: total: %d, used: %d", total, used);
    }
    return ESP_OK;
}

#endif
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

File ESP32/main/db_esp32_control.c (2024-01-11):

/*
 *   This file is part of DroneBridge: https://github.com/seeul8er/DroneBridge
 *
 *   Copyright 2018 Wolfgang Christl
 *
 *   Licensed under the Apache License, Version 2.0 (the "License");
 *   you may not use this file except in compliance with the License.
 *   You may obtain a copy of the License at
 *
 *   http://www.apache.org/licenses/LICENSE-2.0
 *
 *   Unless required by applicable law or agreed to in writing, software
 *   distributed under the License is distributed on an "AS IS" BASIS,
 *   WITHOUT WARRANTIES OR CONDITIONS OF ANY KIND, either express or implied.
 *   See the License for the specific language governing permissions and
 *   limitations under the License.
 *
 */
#include <sys/cdefs.h>
#include <sys/fcntl.h>
#include <sys/param.h>
#include <string.h>
#include <esp_task_wdt.h>
#include <esp_vfs_dev.h>
#include <esp_wifi.h>
#include <lwip/inet.h>
#include <driver/gpio.h>
#include <esp_netif_sta_list.h>
#include "esp_log.h"
#include "lwip/sockets.h"
#include "driver/uart.h"
#include "globals.h"
#include "msp_ltm_serial.h"
#include "db_protocol.h"
#include "tcp_server.h"

#define UART_NUM UART_NUM_1

#define TAG "DB_CONTROL"
#define TRANS_RD_BYTES_NUM  8   // amount of bytes read form serial port at once when transparent is selected
#define UDP_BUF_SIZE    2048
#define UART_BUF_SIZE   (1024)
#define MAX_UDP_CLIENTS 8

struct db_udp_connection_t {
    int udp_socket;
    struct sockaddr_in udp_clients[MAX_UDP_CLIENTS];
    bool is_broadcast[MAX_UDP_CLIENTS];  // sockaddr_in at index is added because of station that connected
};

uint16_t app_port_proxy = APP_PORT_PROXY;
uint8_t ltm_frame_buffer[MAX_LTM_FRAMES_IN_BUFFER * LTM_MAX_FRAME_SIZE];
uint ltm_frames_in_buffer = 0;
uint ltm_frames_in_buffer_pnt = 0;

uint32_t uart_byte_count = 0;
int8_t num_connected_tcp_clients = 0;
int8_t num_connected_udp_clients = 0;

int open_serial_socket() {
    int serial_socket;
    uart_config_t uart_config = {
            .baud_rate = DB_UART_BAUD_RATE,
            .data_bits = UART_DATA_8_BITS,
            .parity    = UART_PARITY_DISABLE,
            .stop_bits = UART_STOP_BITS_1,
            .flow_ctrl = UART_HW_FLOWCTRL_DISABLE
    };
    
    ESP_ERROR_CHECK(uart_param_config(UART_NUM, &uart_config));
    ESP_ERROR_CHECK(uart_set_pin(UART_NUM, GPIO_NUM_21, GPIO_NUM_20, UART_PIN_NO_CHANGE, UART_PIN_NO_CHANGE)); // 'UART_PIN_NO_CHANGE is used for pins that are not used
    ESP_ERROR_CHECK(uart_driver_install(UART_NUM, 1024, 0, 0, NULL, 0));
     
    if ((serial_socket = open("/dev/uart/1", O_RDWR)) == -1) {
        ESP_LOGE(TAG, "Cannot open UART1");
        close(serial_socket);
        uart_driver_delete(UART_NUM);
        return ESP_FAIL;
    }
    esp_vfs_dev_uart_use_driver(1);
    return serial_socket;
}

int open_udp_socket() {
    char addr_str[128];
    int addr_family;
    int ip_protocol;

    struct sockaddr_in server_addr;
    server_addr.sin_addr.s_addr = htonl(INADDR_ANY);
    server_addr.sin_family = AF_INET;
    server_addr.sin_port = htons(APP_PORT_PROXY_UDP);
    addr_family = AF_INET;
    ip_protocol = IPPROTO_IP;
    inet_ntoa_r(server_addr.sin_addr, addr_str, sizeof(addr_str) - 1);

    int udp_socket = socket(addr_family, SOCK_DGRAM, ip_protocol);
    if (udp_socket < 0) {
        ESP_LOGE(TAG, "Unable to create socket: errno %d", errno);
        return -1;
    }
    int err = bind(udp_socket, (struct sockaddr *) &server_addr, sizeof(server_addr));
    if (err < 0) {
        ESP_LOGE(TAG, "Socket unable to bind: errno %d", errno);
    }
    ESP_LOGI(TAG, "Opened UDP socket on port %i", APP_PORT_PROXY_UDP);

    return udp_socket;
}

/**
 * Send to all connected TCP & UDP clients
 *
 * @param tcp_clients
 * @param udp_conn
 * @param data
 * @param data_length
 */
void send_to_all_clients(int tcp_clients[], struct db_udp_connection_t *udp_conn, uint8_t data[], uint data_length) {
    send_to_all_tcp_clients(tcp_clients, data, data_length);
    for (int i = 0; i < MAX_UDP_CLIENTS; i++) {  // send to all UDP clients
        if (udp_conn->udp_clients[i].sin_len > 0) {
            int sent = sendto(udp_conn->udp_socket, data, data_length, 0, (struct sockaddr *) &udp_conn->udp_clients[i],
                              sizeof(udp_conn->udp_clients[i]));
            if (sent != data_length) {
                ESP_LOGE(TAG, "UDP - Error sending (%i/%i) because of %d", sent, data_length, errno);
                udp_conn->udp_clients[i].sin_len = 0;
            }
        }
    }
}

void write_to_uart(const char tcp_client_buffer[], const size_t data_length) {
    int written = uart_write_bytes(UART_NUM, tcp_client_buffer, data_length);
    if (written > 0)
        ESP_LOGD(TAG, "Wrote %i bytes", written);
    else
        ESP_LOGE(TAG, "Error writing to UART %s", esp_err_to_name(errno));
}

/**
 * @brief Parses & sends complete MSP & LTM messages
 */
void parse_msp_ltm(int tcp_clients[], struct db_udp_connection_t *udp_conn, uint8_t msp_message_buffer[],
                   uint *serial_read_bytes,
                   msp_ltm_port_t *db_msp_ltm_port) {
    uint8_t serial_bytes[TRANS_RD_BYTES_NUM];
    uint read;
    if ((read = uart_read_bytes(UART_NUM, serial_bytes, TRANS_RD_BYTES_NUM, 200 / portTICK_RATE_MS)) > 0) {
        uart_byte_count += read;
        for (uint j = 0; j < read; j++) {
            (*serial_read_bytes)++;
            uint8_t serial_byte = serial_bytes[j];
            if (parse_msp_ltm_byte(db_msp_ltm_port, serial_byte)) {
                msp_message_buffer[(*serial_read_bytes - 1)] = serial_byte;
                if (db_msp_ltm_port->parse_state == MSP_PACKET_RECEIVED) {
                    *serial_read_bytes = 0;
                    send_to_all_clients(tcp_clients, udp_conn, msp_message_buffer, *serial_read_bytes);
                } else if (db_msp_ltm_port->parse_state == LTM_PACKET_RECEIVED) {
                    memcpy(&ltm_frame_buffer[ltm_frames_in_buffer_pnt], db_msp_ltm_port->ltm_frame_buffer,
                           (db_msp_ltm_port->ltm_payload_cnt + 4));
                    ltm_frames_in_buffer_pnt += (db_msp_ltm_port->ltm_payload_cnt + 4);
                    ltm_frames_in_buffer++;
                    if (ltm_frames_in_buffer == LTM_FRAME_NUM_BUFFER &&
                        (LTM_FRAME_NUM_BUFFER <= MAX_LTM_FRAMES_IN_BUFFER)) {
                        send_to_all_clients(tcp_clients, udp_conn, ltm_frame_buffer, *serial_read_bytes);
                        ESP_LOGV(TAG, "Sent %i LTM message(s) to telemetry port!", LTM_FRAME_NUM_BUFFER);
                        ltm_frames_in_buffer = 0;
                        ltm_frames_in_buffer_pnt = 0;
                        *serial_read_bytes = 0;
                    }
                }
            }
        }
    }
}
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

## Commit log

2023-11-08 added basic depth based obstacle avoidance
    [steering.py]
2023-11-10 Motor controller
2023-11-22 Copy dronebridge repo from https://github.com/DroneBridge/ESP32
    [partitions.csv]
2023-11-22 Changes to the code to establish serail over UART on ESP32C3
    Changes to the UART port (2 ->1), changes to the proxy, "1604",
2023-11-22 Changes to the UART pin assignment, to receive information flight controller
2023-11-24 added a simple version of the obstacle avoidance algorithm
    [steering_basic.py]
2023-12-03 changed the camera settings to reduce motion blur
2023-12-03 changed camera settings for steering
2023-12-03 mode switching
2023-12-04 Add some essential mavlink message handler to give:
    - voltage
    - current
    - speed
    - encode,current data from pico
2023-12-05 Add Software serial class
    - Required for communication with FC as exsiting 2 uarts are insufficient
2023-12-05 Add standardised protocol for interpico comms
    - Required to allow current values to be passed between picos
2023-12-05 Enable current readings from pico to Flight controller
    - Refactor communication methods between cntral hub and controller to use the standardised protocol
2023-12-05 Update code for stripboard layout
    - Receiver - Changed for more compact layout
    - Central_UART -Changed due to GND shorted with 8/9 pin pair
    [central_hub.py, motor_controller.py, receiver.py]
2023-12-05 Fix uart bug in mavlite that initialises with default pin
    [mavlite.py, uart.py]
2023-12-05 Chnage central_hub to match latest mavlink implementation
    - Use asyncio for main loop in central hub
    - Respond to sensor data instead of requesting them to reduce chances of failure
    - Scrape handshake wait as it does not contribute much at the moment
    - The driver can be put to disable by just sending drive(0,0) or e-stop
    [central_hub.py, mav_bridge.py]
2023-12-05 Refactor motor_controller
    - Remove handshake together with the changes in central_hub
    - Add constant sensor data broadcast methods
    - Commented out pid as it is not stable yet
2023-12-05 Allow more robust overcurrent handling
    - Switch the order of motor id (hardware wiring)
2023-12-05 Allow PID to be stopped in deadzone
    - Further tune PID constants for period of 200ms
2023-12-05 Reduce baudrate for softuart to reduce the load on pico
    - Reduce the lost packets as well
2023-12-05 Replace Exception with bounded input
    [sabertooth.py]
2023-12-05 Increase the pulse timeout for pwm
    - Ensure the pulse is captured by the pico
2023-12-05 Add methods to check the status of receiver and encoder
2023-12-05 Update hardware change in the pins
    - The estop becomes active high because of the transistor switching circuit
2023-12-05 Modify PPR
    - Formula: gear ratio * motor PPR * 4 (51*12*4=2448)
2023-12-05 Increase sensor update rate, pid output range and deadzone
    - Fix typo and remove unused code
    [motor_controller.py]
2023-12-05 Prevent hardware interrupt firing before memory allocation
    [ppm_reader.py]
2023-12-05 Implement clipping output instead of driving to 0 immediately
    - Avoid issue that might damage the gearbox if the output oscillates between 0-100
    [motor_controller.py]
2023-12-07 Fix bug in output_map method
    [motor_controller.py]
2023-12-07 steering tuning
2023-12-07 Fix missing message issue
    - Wait for the message using recv_match for a maximum of timeout second
    [mav_listener.py]
2023-12-07 Allow additional conditions for mavlink messages from pico
2023-12-07 Fix flight controller mode function
    [mav_listener.py]
2023-12-08 Filter heartbeat from rover only
2023-12-08 fixed camera settings and gps usb port
    [data_collection.py]
2023-12-11 hole filling filter, obstacle detection
2023-12-11 added threshold filter to the depth image
2023-12-14 added different versions of steering to test mavlink commands
2023-12-15 post processing filters applied to depth image
2023-12-18 added hole filling to spatial filter, distance calculation from depth image
2023-12-19 get the latest frames from camera
2023-12-19 Fix motor id and rotation direction at low level
    - Ensure that it is consistent wih the motor wiring
    [motor_controller.py]
2023-12-19 Allow motor controller to parse all messages in buffer
    - Prevent out of sync movement between front and rear wheels
    [motor_controller.py]
2023-12-19 Add avergae filter to rc input in direct rc mode
    - Add timeout paramter to Receiver class
2023-12-19 Add more print to pid test method
2023-12-19 Ensure the correctness of current measurement
    - Forward gives positive current and vice versa
    - Add invert_current argument to Sensor class
    [motor.py, motor_controller.py]
2023-12-20 testing tall vegetation and collision detection
    [steering_basic.py]
2023-12-20 Add wheel distance getter
2023-12-20 Add hysteresis to prevent going from 0 to full speed in one iteration
    [motor_controller.py]
2023-12-20 Add disconnect timeout from central pico
2023-12-20 Add missing await for sending sensor data
    [central_hub.py]
2023-12-20 Add RC disconnect failsafe in low level controller
    [central_hub.py]
2023-12-20 changed deadend threshold, implemented collision and tall vegetation detection
    [steering_basic.py]
2023-12-22 increased rgb gain, set threshold filter to 4m to ignore variation in background for steering
2023-12-30 getting IMU data with mav_listener
2024-01-05 Add functions to switch between different gps types
2024-01-05 print slope
2024-01-05 print angle
2024-01-06 Rename motor.py
2024-01-07 Change serial port on FC
    - UART on rpi5 doesnt work out of the box
2024-01-07 Rename serial0 to ttyAMA0
    - In rpi5 serial0 points to the UART connector instead
    - See https://forums.raspberrypi.com/viewtopic.php?p=2176627#p2176529
2024-01-08 Round pwm to integer
2024-01-08 set correct sigma values for semantic
    [semantic_map.py]
2024-01-15 stopped aligning, reduced speed threshold for tall vegetation, only 1 cases possible/frame
2024-01-15 removed slope grid prints
2024-01-15 changed collision threshold speed
    [navigation_final.py]
2024-01-17 back command and collision testing
    [back_command_testing.py]
2024-01-18 fixed going back command
    [navigation_final.py]
2024-01-18 switch to AUTO before navigation for initial alignment towards the waypoint. added for completeness and my sanity
2024-01-29 Initial commit
    - Includes pico library from https://github.com/ncarandini/KiCad-RP-Pico
    - Some schematic on motor controller around pico
    [central_hub.kicad_sch, low_level_control.kicad_sch, motor_controller.kicad_sch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]
2024-01-29 Complete motor controller schematic
    [low_level_control.kicad_sch, motor_controller.kicad_sch, rover.kicad_pcb]
2024-01-29 Complete Central Hub schematic
    [central_hub.kicad_sch, low_level_control.kicad_sch]
2024-01-29 Update connection between picos
    [central_hub.kicad_sch, low_level_control.kicad_sch, motor_controller.kicad_sch]
2024-01-29 Complete power board and motor wiring
    [low_level_control.kicad_sch, motor_controller.kicad_sch, power_supply.kicad_sch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]
2024-01-29 Arrange components following the stripboard layout
    [central_hub.kicad_sch, rover.kicad_pcb]
2024-01-29 Increase uncapped current threshold
2024-07-16 Rover localisation and minor fixes
    [back_command_testing.py, camera_angle.py, data_collection.py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]
2024-10-24 Added CAD Files
    [Back v6.f3d, Bottom.stl, Cable Housing v2.f3z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]
